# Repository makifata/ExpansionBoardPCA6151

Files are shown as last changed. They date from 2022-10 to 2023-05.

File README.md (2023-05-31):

# ExpansionBoardPCA6151
PCA-6151 does work with 5V / 12V supply with four pin connector. However, 
Peripheral board on ISA bus will need negative voltage such as -12 or -5V. 
This Repo is the custom ISA expansion board which distribute -12V and -5V from ATX power.

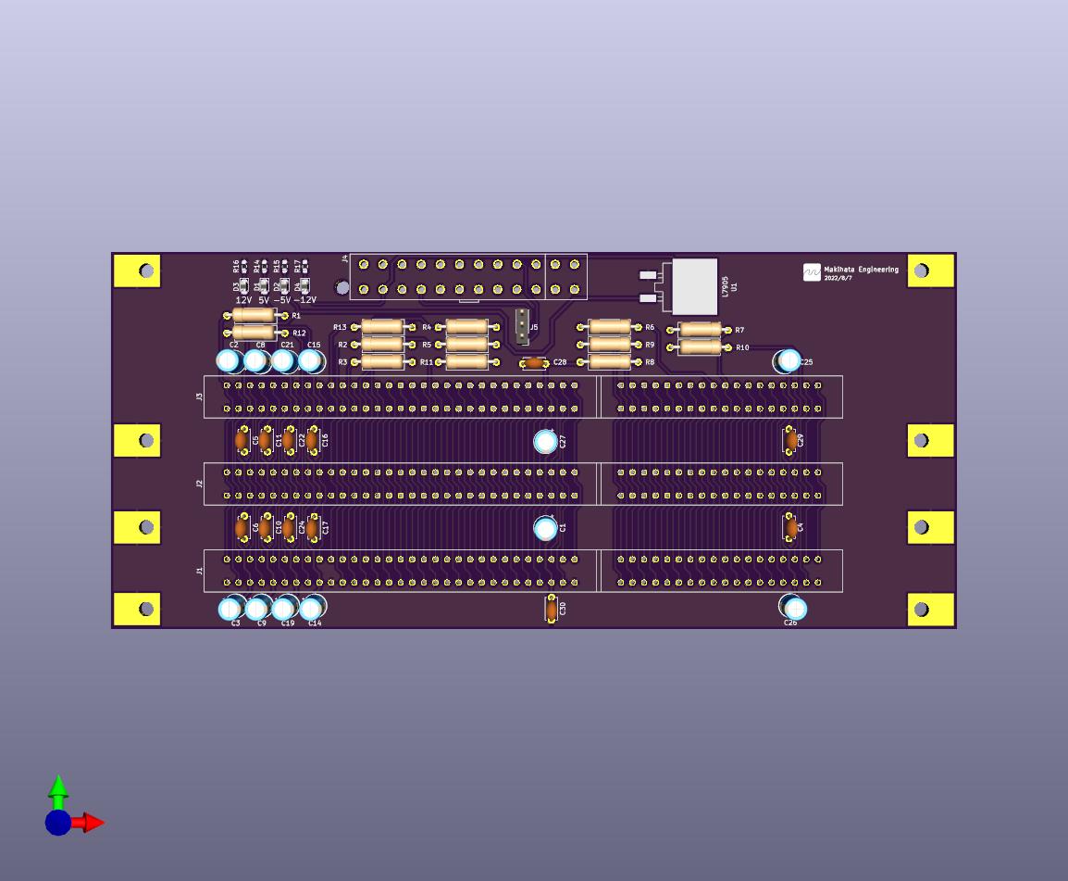
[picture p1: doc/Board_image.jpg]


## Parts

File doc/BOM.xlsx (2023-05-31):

Index | Quantity | Part Number | Manufacturer Part Number | Description | Customer Reference | Backorder | Unit Price | Extended Price
1 | 6 | EDC395982-ND | 395-098-520-350 | CONN EDGE DUAL FMALE 98POS 0.100 |  | 0 | 3.7 | $22.20
2 | 2 | 497-7292-1-ND | L7905ACD2T-TR | IC REG LINEAR -5V 1.5A D2PAK |  | 0 | 1.11 | $2.22
3 | 2 | A127799-ND | 1-1775099-3 | CONN RCPT 24POS 0.165 TIN PCB |  | 0 | 1.08 | $2.16
4 | 2 | LT1584CT#PBF-ND | LT1584CT#PBF | IC REG LINEAR POS ADJ 7A TO220-3 |  | 0 | 14.11 | $28.22
5 | 10 | 478-10723-1-ND | F931C106KAAAJ6 | CAP TANT 10UF 10% 16V 1206 |  | 0 | 0.615 | $6.15
6 | 10 | 399-A766KE476M1DLAE045CT-ND | A766KE476M1DLAE045 | CAP ALUM POLY 47UF 20% 20V SMD |  | 0 | 0.566 | $5.66
 |  |  |  |  |  |  | Subtotal | $66.61

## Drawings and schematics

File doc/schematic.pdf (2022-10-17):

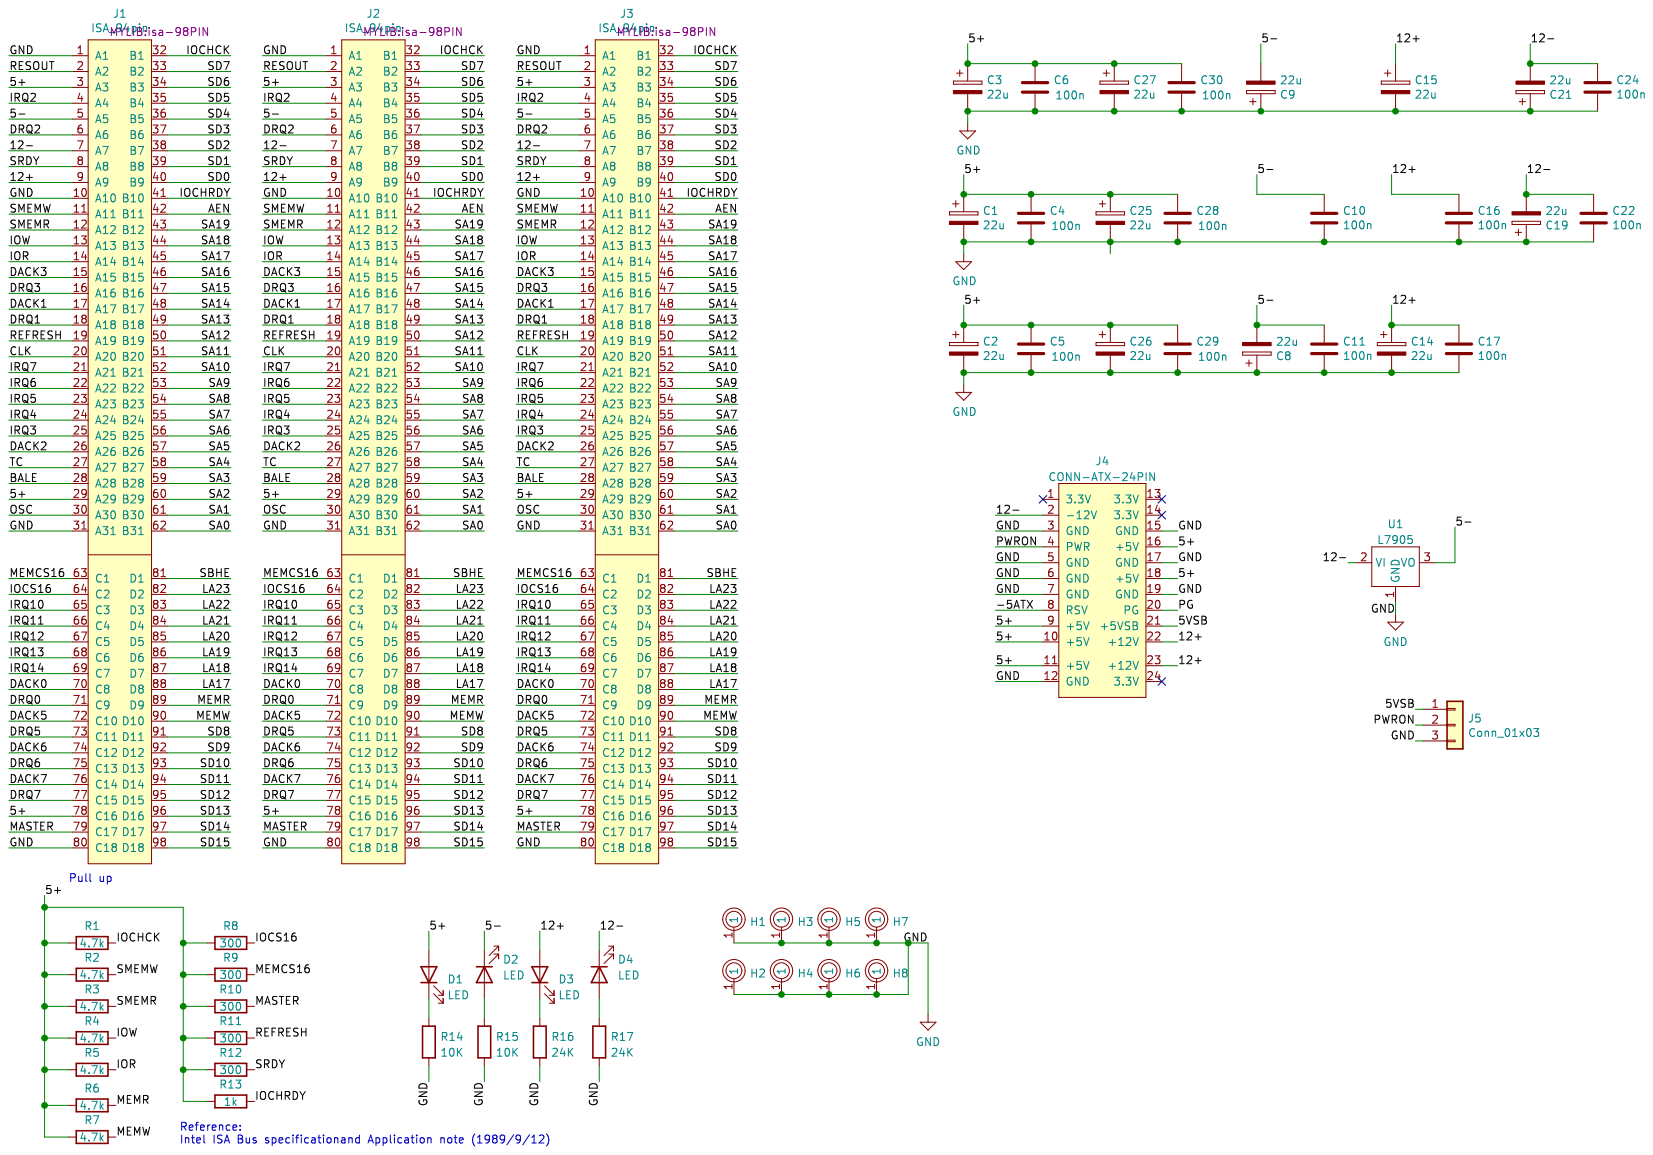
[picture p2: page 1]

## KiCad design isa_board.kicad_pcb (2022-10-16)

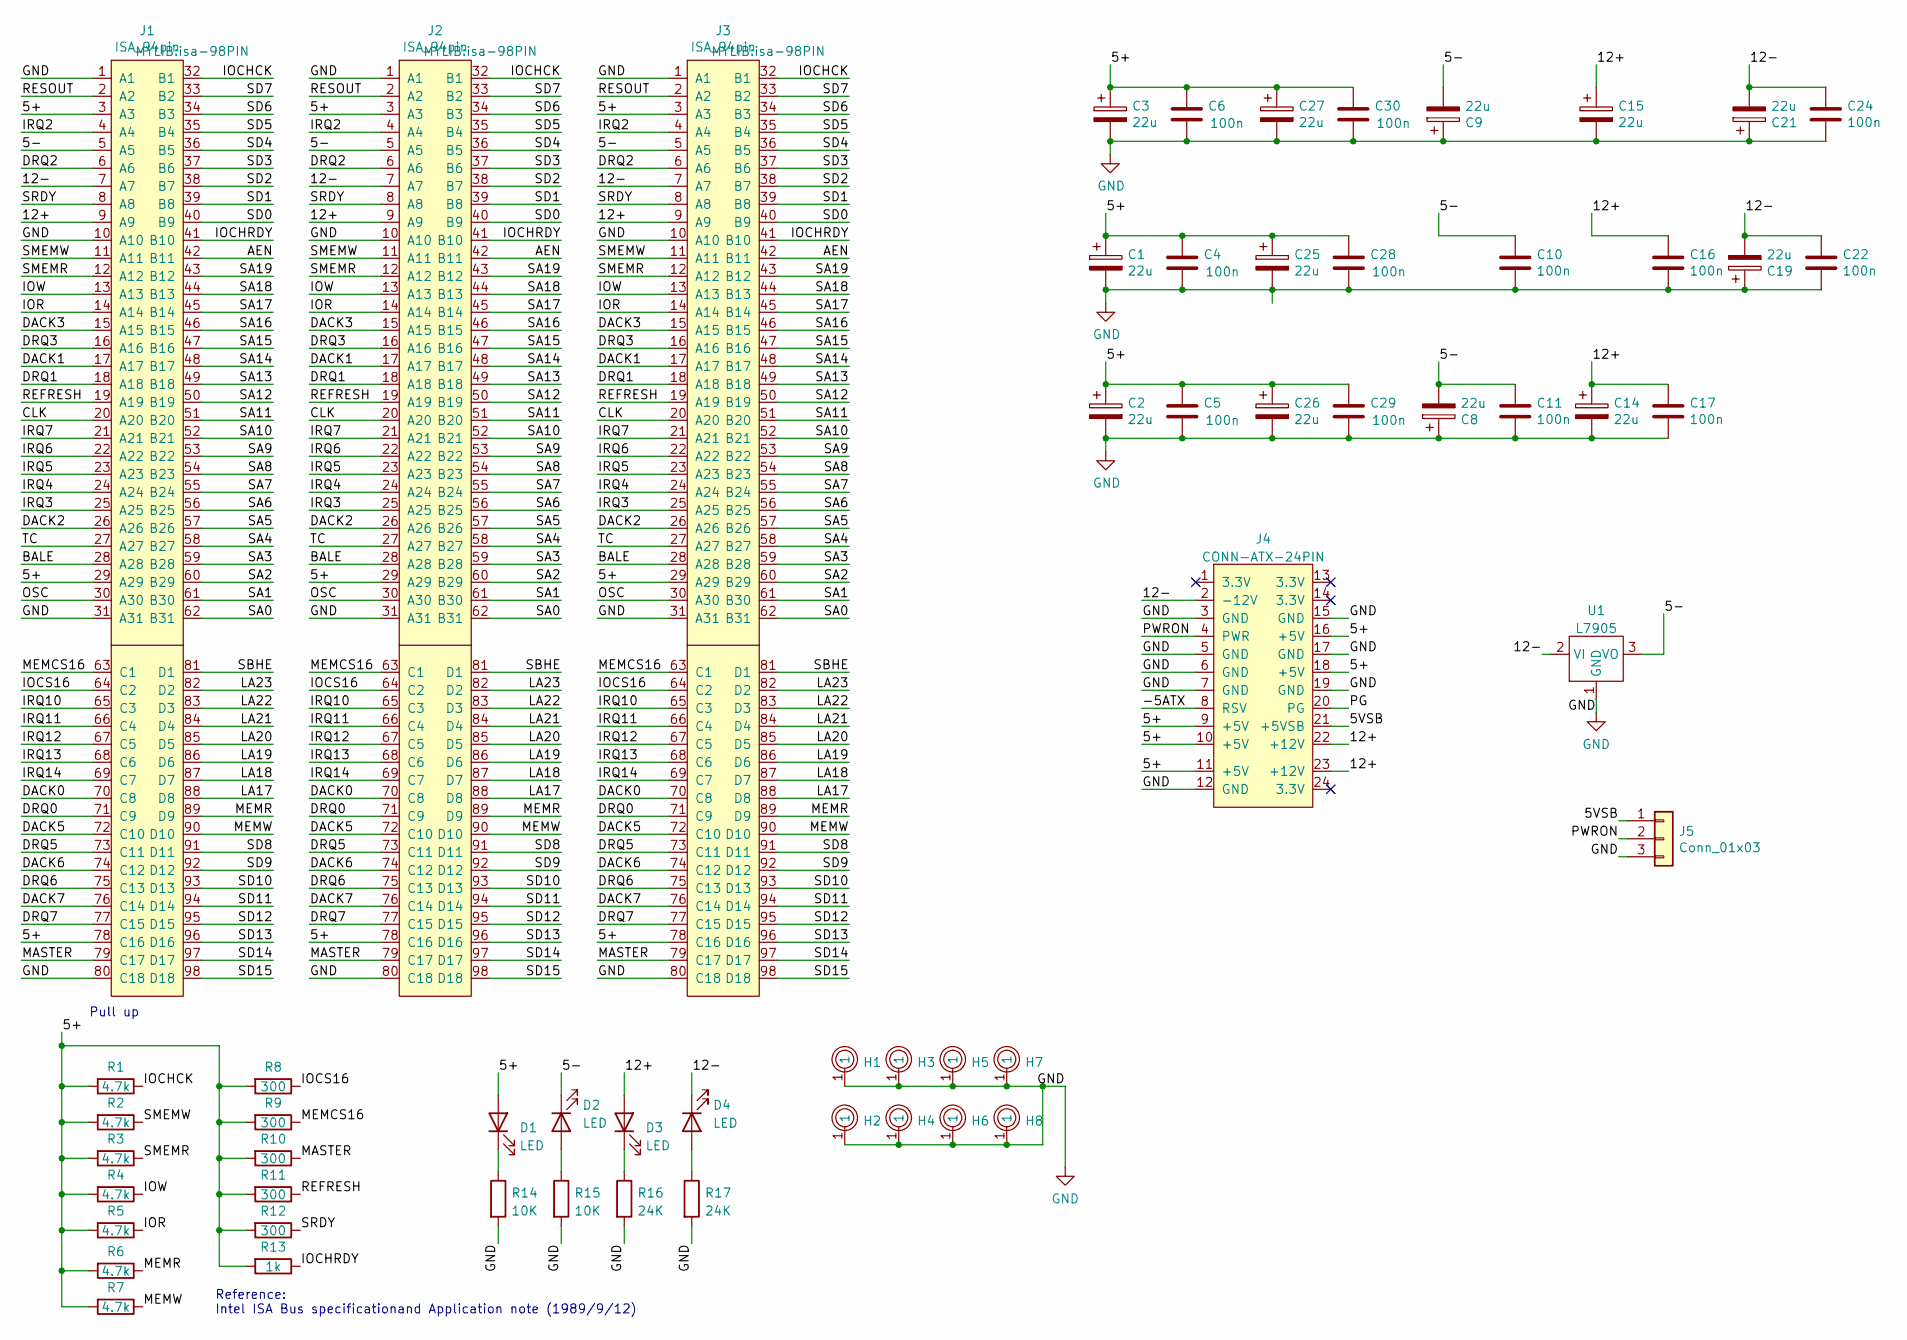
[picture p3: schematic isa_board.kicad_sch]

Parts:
C1, C2, C3, C8, C9, C14, C15, C19, C21, C25, C26, C27: 22u; CP_Radial_D5.0mm_P2.00mm
C4, C5, C6, C10, C11, C16, C17, C22, C24, C28, C29, C30: 100n; C_Disc_D4.7mm_W2.5mm_P5.00mm
D1, D2, D3, D4: LED; D_0805_2012Metric_Pad1.15x1.40mm_HandSolder
H1, H2, H3, H4, H5, H6, H7, H8: MountHole; RightAngle
J1, J2, J3: ISA_94pin; isa-98PIN
J4: CONN-ATX-24PIN; atx-24PIN
J5: Conn_01x03; PinHeader_1x03_P2.54mm_Vertical
R1, R2, R3, R4, R5, R6, R7: 4.7k; R_Axial_DIN0309_L9.0mm_D3.2mm_P12.70mm_Horizontal
R8, R9, R10, R11, R12: 300; R_Axial_DIN0309_L9.0mm_D3.2mm_P12.70mm_Horizontal
R13: 1k; R_Axial_DIN0309_L9.0mm_D3.2mm_P12.70mm_Horizontal
R14, R15: 10K; R_0603_1608Metric_Pad0.98x0.95mm_HandSolder
R16, R17: 24K; R_0603_1608Metric_Pad0.98x0.95mm_HandSolder
U1: L7905; L7905ACD2T-TR

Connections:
/5+: C1.1, C2.1, C3.1, C4.1, C5.1, C6.1, C25.1, C26.1, C27.1, C28.1, C29.1, C30.1, D1.2 (A), J1.3 (A3), J1.29 (A29), J1.78 (C16), J2.3 (A3), J2.29 (A29), J2.78 (C16), J3.3 (A3), J3.29 (A29), J3.78 (C16), J4.9 (+5V), J4.10 (+5V), J4.11 (+5V), J4.16 (+5V), J4.18 (+5V), R1.2, R2.2, R3.2, R4.2, R5.2, R6.2, R7.2, R8.2, R9.2, R10.2, R11.2, R12.2, R13.2
/5VSB: J4.21 (+5VSB), J5.1
/12+: C14.1, C15.1, C16.1, C17.1, D3.2 (A), J1.9 (A9), J2.9 (A9), J3.9 (A9), J4.22 (+12V), J4.23 (+12V)
/-5ATX: J4.8 (RSV)
/AEN: J1.42 (B11), J2.42 (B11), J3.42 (B11)
/BALE: J1.28 (A28), J2.28 (A28), J3.28 (A28)
/CLK: J1.20 (A20), J2.20 (A20), J3.20 (A20)
/DACK0: J1.70 (C8), J2.70 (C8), J3.70 (C8)
/DACK1: J1.17 (A17), J2.17 (A17), J3.17 (A17)
/DACK2: J1.26 (A26), J2.26 (A26), J3.26 (A26)
/DACK3: J1.15 (A15), J2.15 (A15), J3.15 (A15)
/DACK5: J1.72 (C10), J2.72 (C10), J3.72 (C10)
/DACK6: J1.74 (C12), J2.74 (C12), J3.74 (C12)
/DACK7: J1.76 (C14), J2.76 (C14), J3.76 (C14)
/DRQ0: J1.71 (C9), J2.71 (C9), J3.71 (C9)
/DRQ1: J1.18 (A18), J2.18 (A18), J3.18 (A18)
/DRQ2: J1.6 (A6), J2.6 (A6), J3.6 (A6)
/DRQ3: J1.16 (A16), J2.16 (A16), J3.16 (A16)
/DRQ5: J1.73 (C11), J2.73 (C11), J3.73 (C11)
/DRQ6: J1.75 (C13), J2.75 (C13), J3.75 (C13)
/DRQ7: J1.77 (C15), J2.77 (C15), J3.77 (C15)
/IOCHCK: J1.32 (B1), J2.32 (B1), J3.32 (B1), R1.1
/IOCHRDY: J1.41 (B10), J2.41 (B10), J3.41 (B10), R13.1
/IOCS16: J1.64 (C2), J2.64 (C2), J3.64 (C2), R8.1
/IOR: J1.14 (A14), J2.14 (A14), J3.14 (A14), R5.1
/IOW: J1.13 (A13), J2.13 (A13), J3.13 (A13), R4.1
/IRQ2: J1.4 (A4), J2.4 (A4), J3.4 (A4)
/IRQ3: J1.25 (A25), J2.25 (A25), J3.25 (A25)
/IRQ4: J1.24 (A24), J2.24 (A24), J3.24 (A24)
/IRQ5: J1.23 (A23), J2.23 (A23), J3.23 (A23)
/IRQ6: J1.22 (A22), J2.22 (A22), J3.22 (A22)
/IRQ7: J1.21 (A21), J2.21 (A21), J3.21 (A21)
/IRQ10: J1.65 (C3), J2.65 (C3), J3.65 (C3)
/IRQ11: J1.66 (C4), J2.66 (C4), J3.66 (C4)
/IRQ12: J1.67 (C5), J2.67 (C5), J3.67 (C5)
/IRQ13: J1.68 (C6), J2.68 (C6), J3.68 (C6)
/IRQ14: J1.69 (C7), J2.69 (C7), J3.69 (C7)
/LA17: J1.88 (D8), J2.88 (D8), J3.88 (D8)
/LA18: J1.87 (D7), J2.87 (D7), J3.87 (D7)
/LA19: J1.86 (D6), J2.86 (D6), J3.86 (D6)
/LA20: J1.85 (D5), J2.85 (D5), J3.85 (D5)
/LA21: J1.84 (D4), J2.84 (D4), J3.84 (D4)
/LA22: J1.83 (D3), J2.83 (D3), J3.83 (D3)
/LA23: J1.82 (D2), J2.82 (D2), J3.82 (D2)
/MASTER: J1.79 (C17), J2.79 (C17), J3.79 (C17), R10.1
/MEMCS16: J1.63 (C1), J2.63 (C1), J3.63 (C1), R9.1
/MEMR: J1.89 (D9), J2.89 (D9), J3.89 (D9), R6.1
/MEMW: J1.90 (D10), J2.90 (D10), J3.90 (D10), R7.1
/OSC: J1.30 (A30), J2.30 (A30), J3.30 (A30)
/PG: J4.20 (PG)
/PWRON: J4.4 (PWR), J5.2
/REFRESH: J1.19 (A19), J2.19 (A19), J3.19 (A19), R11.1
/RESOUT: J1.2 (A2), J2.2 (A2), J3.2 (A2)
/SA0: J1.62 (B31), J2.62 (B31), J3.62 (B31)
/SA1: J1.61 (B30), J2.61 (B30), J3.61 (B30)
/SA2: J1.60 (B29), J2.60 (B29), J3.60 (B29)
/SA3: J1.59 (B28), J2.59 (B28), J3.59 (B28)
/SA4: J1.58 (B27), J2.58 (B27), J3.58 (B27)
/SA5: J1.57 (B26), J2.57 (B26), J3.57 (B26)
/SA6: J1.56 (B25), J2.56 (B25), J3.56 (B25)
/SA7: J1.55 (B24), J2.55 (B24), J3.55 (B24)
/SA8: J1.54 (B23), J2.54 (B23), J3.54 (B23)
/SA9: J1.53 (B22), J2.53 (B22), J3.53 (B22)
/SA10: J1.52 (B21), J2.52 (B21), J3.52 (B21)
/SA11: J1.51 (B20), J2.51 (B20), J3.51 (B20)
/SA12: J1.50 (B19), J2.50 (B19), J3.50 (B19)
/SA13: J1.49 (B18), J2.49 (B18), J3.49 (B18)
/SA14: J1.48 (B17), J2.48 (B17), J3.48 (B17)
/SA15: J1.47 (B16), J2.47 (B16), J3.47 (B16)
/SA16: J1.46 (B15), J2.46 (B15), J3.46 (B15)
/SA17: J1.45 (B14), J2.45 (B14), J3.45 (B14)
/SA18: J1.44 (B13), J2.44 (B13), J3.44 (B13)
/SA19: J1.43 (B12), J2.43 (B12), J3.43 (B12)
/SBHE: J1.81 (D1), J2.81 (D1), J3.81 (D1)
/SD0: J1.40 (B9), J2.40 (B9), J3.40 (B9)
/SD1: J1.39 (B8), J2.39 (B8), J3.39 (B8)
/SD2: J1.38 (B7), J2.38 (B7), J3.38 (B7)
/SD3: J1.37 (B6), J2.37 (B6), J3.37 (B6)
/SD4: J1.36 (B5), J2.36 (B5), J3.36 (B5)
/SD5: J1.35 (B4), J2.35 (B4), J3.35 (B4)
/SD6: J1.34 (B3), J2.34 (B3), J3.34 (B3)
/SD7: J1.33 (B2), J2.33 (B2), J3.33 (B2)
/SD8: J1.91 (D11), J2.91 (D11), J3.91 (D11)
/SD9: J1.92 (D12), J2.92 (D12), J3.92 (D12)
/SD10: J1.93 (D13), J2.93 (D13), J3.93 (D13)
/SD11: J1.94 (D14), J2.94 (D14), J3.94 (D14)
/SD12: J1.95 (D15), J2.95 (D15), J3.95 (D15)
/SD13: J1.96 (D16), J2.96 (D16), J3.96 (D16)
/SD14: J1.97 (D17), J2.97 (D17), J3.97 (D17)
/SD15: J1.98 (D18), J2.98 (D18), J3.98 (D18)
/SMEMR: J1.12 (A12), J2.12 (A12), J3.12 (A12), R3.1
/SMEMW: J1.11 (A11), J2.11 (A11), J3.11 (A11), R2.1
/SRDY: J1.8 (A8), J2.8 (A8), J3.8 (A8), R12.1
/TC: J1.27 (A27), J2.27 (A27), J3.27 (A27)
GND: C1.2, C2.2, C3.2, C4.2, C5.2, C6.2, C8.1, C9.1, C10.2, C11.2, C14.2, C15.2, C16.2, C17.2, C19.1, C21.1, C22.2, C24.2, C25.2, C26.2, C27.2, C28.2, C29.2, C30.2, H1.1, H2.1, H3.1, H4.1, H5.1, H6.1, H7.1, H8.1, J1.1 (A1), J1.10 (A10), J1.31 (A31), J1.80 (C18), J2.1 (A1), J2.10 (A10), J2.31 (A31), J2.80 (C18), J3.1 (A1), J3.10 (A10), J3.31 (A31), J3.80 (C18), J4.3 (GND), J4.5 (GND), J4.6 (GND), J4.7 (GND), J4.12 (GND), J4.15 (GND), J4.17 (GND), J4.19 (GND), J5.3, R14.2, R15.2, R16.2, R17.2, U1.1 (GND)
unnamed: D1.1 (K), R14.1
unnamed: D3.1 (K), R16.1

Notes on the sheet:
Reference: Intel ISA Bus specificationand Application note (1989/9/12)
Pull up

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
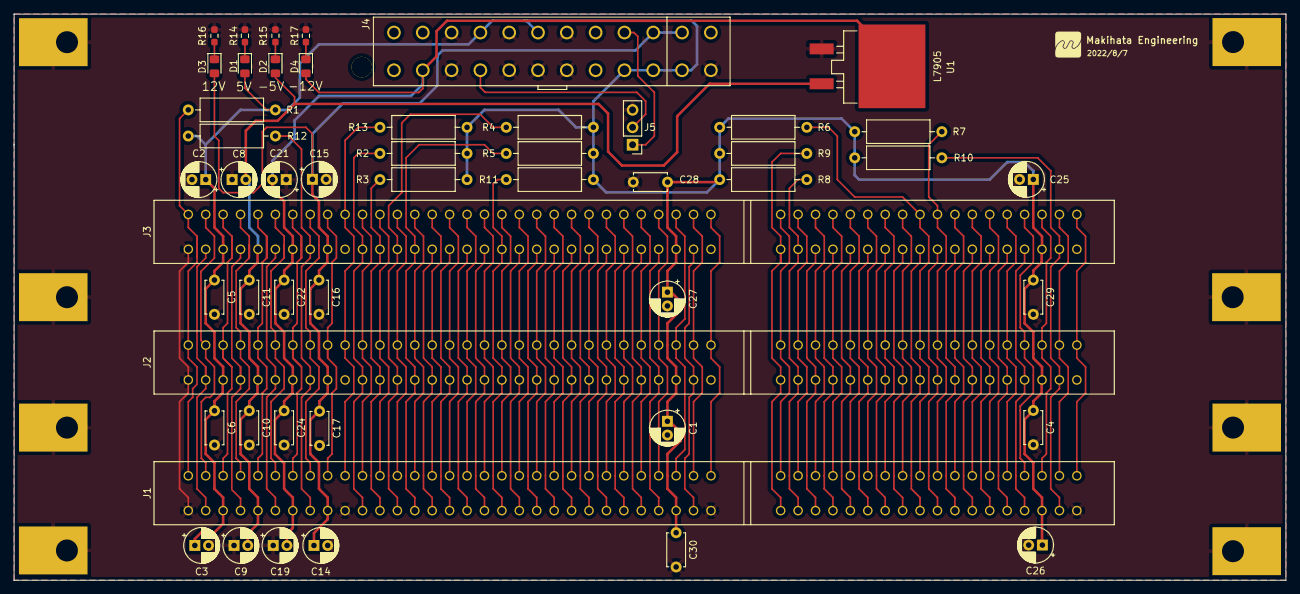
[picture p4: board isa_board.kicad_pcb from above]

Board: 2 copper layers, 185.4 x 82.5 mm, 59 parts (0 on the bottom side), 99 nets.

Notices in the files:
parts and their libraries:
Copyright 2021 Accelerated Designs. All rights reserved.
